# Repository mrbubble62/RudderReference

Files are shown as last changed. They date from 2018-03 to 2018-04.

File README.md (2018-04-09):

# Rudder Reference
Low cost NMEA 2000 compatible rudder reference.

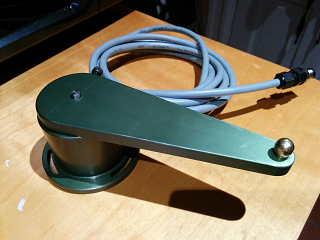
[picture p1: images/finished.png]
Finished
   

## PGN's sent 
127245 Rudder angle in radians every 250ms.

## Initial calibration via USB serial
Center the sensor and press 'z' to set zero angle, turn 90 degrees and use the + and - keys to adjust gain.

## Zero setting in vessel
Center the rudder and from an MFD change the device instance to 200.
The current setting will be stored in EEPROM as the zero point.
The device will return to the prevoiusly set N2K device instance, this may confuse the MFD so power cycle the system.

### Tested Hardware
- Teensy 3.2
- MCP2562 CAN Transceiver
- LM7805 5V Linear regulator
- 0.25A Poly fuse
- 5K ohm Linear 0.1% WDD35D4-5K Angle Sensors

## Notes
WDD35D4 Angle Sensor potentiometers claim a reliable plastic track with good linearity and are availible on eBay for ~$10.
Teensy ADC is good for 12-13bits giving a resolution of 0.04-0.08 degrees.

## Prototype images
Ugly but functional prototype  
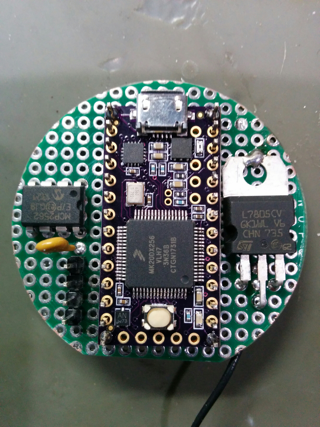
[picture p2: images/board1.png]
   
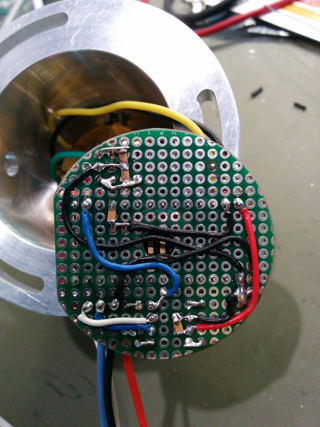
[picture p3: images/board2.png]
   
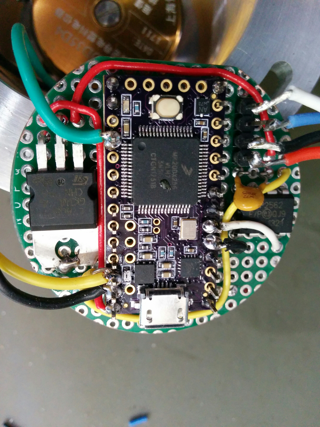
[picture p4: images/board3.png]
   
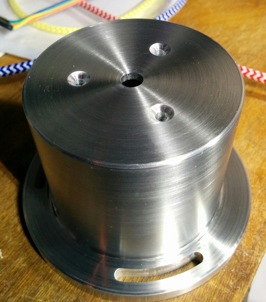
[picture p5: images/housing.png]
   
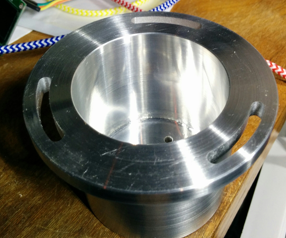
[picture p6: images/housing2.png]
   
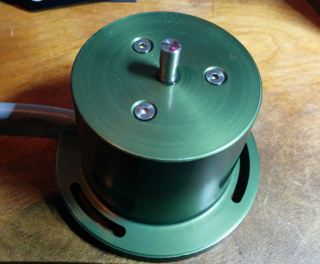
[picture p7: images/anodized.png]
   
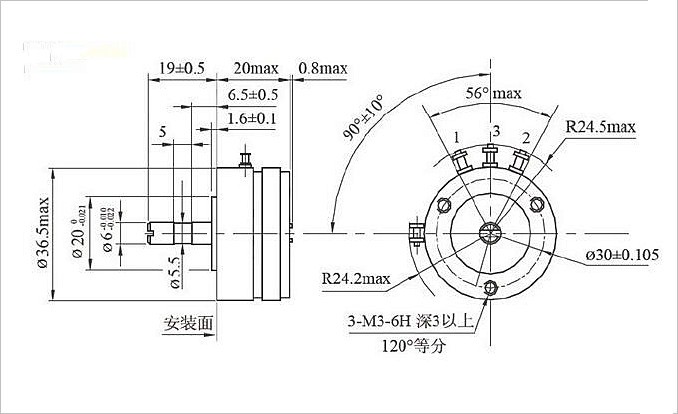
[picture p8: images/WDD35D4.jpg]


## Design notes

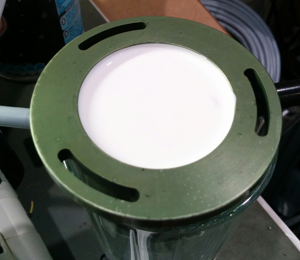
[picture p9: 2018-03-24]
images/RTV.png

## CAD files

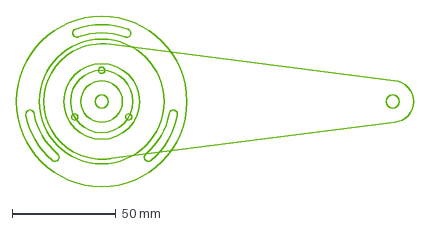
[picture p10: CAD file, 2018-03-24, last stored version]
RudderRefrence.dxf
191.0 x 82.0 mm

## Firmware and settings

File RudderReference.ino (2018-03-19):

#include "NMEA2000_CAN.h"
#include "N2kMessages.h"
#include <EEPROM.h>
#include <ADC_Module.h>
#include <ADC.h>

#define EEPROM_ADDR_CONFIG 0 // starting eeprom address for config params (Teensy 2K EEPROM) 
#define STDBYPIN 14 // MCP2562 CAN tranciver standby
#define ADCRESOLUTION 16
#define DEG2RAD 0.01745329252
#define ADCNUM 1 // ADC 1 seems slightly less noisy
const uint8_t ADCPIN = PIN_A2; // ADC0 or 1
double scale = 0.00950; // volts per degree
double VREF = 3.307;	// measured ADC Reference voltage
double offsetVoltage;	// center point voltage offset
double position;		//angle in degrees
uint16_t adcCount = 0; // ADC value in counts
double volts = 0; // measured ADC voltage
double gain = 1.000;  // sensor gain  compensate for potentiometer accuracy 5K 5%
ADC* adc = new ADC();
float average = 0;
const int NUM_AVGS = 100;

// VREF_OUT test function
float GetVREF() {
	average = 0;
	for (int i = 0; i<NUM_AVGS; i++) {
		average += 1.195 / adc->analogRead(ADC_INTERNAL_SOURCE::VREF_OUT, ADCNUM)*(adc->getMaxValue(ADCNUM));
	}
	return average / NUM_AVGS;
}

// VREFH test function
float GetVREFH() {
	average = 0;
	for (int i = 0; i<NUM_AVGS; i++) {
		average += VREF / adc->analogRead(ADC_INTERNAL_SOURCE::VREFH, ADCNUM)*(adc->getMaxValue(ADCNUM));
	}
	return average / NUM_AVGS;
}

// EEPROM configuration structure
#define MAGIC 12345 // EPROM struct version check, change this whenever tConfig structure changes
struct tConfig {
	uint16_t Magic; //test if eeprom initialized
	double Zero;
	double Gain;
	uint8_t deviceInstance;
};

// EEPROM contents
tConfig config;

// Default EEPROM contents
const tConfig defConfig PROGMEM = {
	MAGIC,
	VREF/2, // zero
	1,  // unity gain
	50	// deviceInstance
};

//*****************************************************************************
tN2kMsg N2kMsg; // N2K message constructor
const unsigned long TransmitMessages[] PROGMEM = { 127245L, 0 }; //Rudder Angle																						   // 	Received Messages			

void setup() {
	pinMode(LED_BUILTIN, OUTPUT); //enable LED
	pinMode(STDBYPIN, OUTPUT);  // take CAN chip out of standby
	digitalWrite(STDBYPIN, LOW);
	pinMode(ADCPIN, INPUT);
	Serial.begin(115200);
	Blink(10, 250); //delay for 1 sec and flash LED

	adc->setReference(ADC_REFERENCE::REF_3V3, ADCNUM);
	adc->setAveraging(32, ADCNUM);
	adc->setResolution(ADCRESOLUTION, ADCNUM);
	adc->setConversionSpeed(ADC_CONVERSION_SPEED::VERY_LOW_SPEED, ADCNUM);
	adc->setSamplingSpeed(ADC_SAMPLING_SPEED::VERY_LOW_SPEED, ADCNUM);
	adc->startContinuous(ADCPIN, ADCNUM);
	delay(100);
	Serial.println(F("STARTING"));
	ReadConfig();
	if (config.Magic != MAGIC) {
		InitializeEEPROM();
		Serial.println(F("No stored calibration..\n"));
		delay(5000);
	}
	else {
		Serial.println(F("Loading stored calibration..\n"));
		PrintConfig();
		gain = config.Gain;
		offsetVoltage = config.Zero;
	}
	
	// report the supply voltages
	Serial.print(F("3.3V ADC reference : "));
	Serial.print(GetVREFH(),4);
	Serial.println("V");
	Serial.print("VREF OUT voltage: ");
	Serial.print(GetVREF(), 4);
	Serial.println("V");	delay(2000);

	// Setup NMEA2000
	NMEA2000.SetInstallationDescription1("Mr Bubble Rudder Reference");
	NMEA2000.SetProductInformation("20180317", // Manufacturer's Model serial code
		669, // Manufacturer's product code
		"Rudder Reference",  // Manufacturer's Model ID
		"1.0.0.0",  // Manufacturer's Software version code
		"1.0.0.0", // Manufacturer's Model version
		2,	// load equivalency *50ma
		0xffff, // NMEA 2000 version - use default
		0xff // Sertification level - use default
	);
	// Set device information
	NMEA2000.SetDeviceInformation(20180317, // Unique number. Use e.g. Serial number.
		155, // Device function=Environment See codes on http://www.nmea.org/Assets/20120726%20nmea%202000%20class%20%26%20function%20codes%20v%202.00.pdf
		40, // Device class=Sensor Communication Interface. See codes on http://www.nmea.org/Assets/20120726%20nmea%202000%20class%20%26%20function%20codes%20v%202.00.pdf
		2040, // Just choosen free from code list on http://www.nmea.org/Assets/20121020%20nmea%202000%20registration%20list.pdf                               
		4 // marine industry
	);
	NMEA2000.SetMode(tNMEA2000::N2km_NodeOnly, config.deviceInstance);
	NMEA2000.EnableForward(false);
	NMEA2000.ExtendTransmitMessages(TransmitMessages);
	NMEA2000.SetN2kCANMsgBufSize(5);
	NMEA2000.Open();
	PrintHelp();
}

// loop controls
uint32_t delt_t = 0; // 250 ms loop
uint32_t count = 0; // 250 ms loop
long slowloop = 0; // 1s loop

// USB serial commands
bool SDEBUG = false; // toggle debug print
bool SDATA = false; // toggle data print
int GAIN; // gain switch

void loop() {
	char command = getCommand();
	switch (command) {
	case '+':
		GAIN = 1;
		break;
	case '-':
		GAIN = -1;
		break;
	case 'd':
		SDEBUG = !SDEBUG;
		break;
	case 'w':
		config.Gain = gain;
		UpdateConfig();
		break;
	case 'z': 
		offsetVoltage = volts;
		config.Zero = offsetVoltage;
		UpdateConfig();
		break;
	default:
		break;
	}

	if (adc->isComplete(ADCNUM)) {
		adcCount = (uint16_t)adc->analogReadContinuous(ADCNUM);
	}

	// 250ms 
	delt_t = millis() - count;
	if (delt_t > 250) { // fast update once per 250ms independent of read rate
		count = millis();
		digitalWrite(LED_BUILTIN, LOW);

		if (GAIN != 0) {
			SDATA = true;
			gain += (gain / 500)*GAIN;
			Serial.print("GAIN: ");
			Serial.println(gain);
			GAIN = 0;
		}

		volts = adcCount * VREF / (double)adc->getMaxValue(ADCNUM);
		position = gain * (volts - offsetVoltage)/scale;
		
		// debug
		if (SDEBUG) { printDebug(); }
		if (SDATA) { print(); }

		// send rudder angle 
		SetN2kRudder(N2kMsg, position*DEG2RAD);
		NMEA2000.SendMsg(N2kMsg);

		slowloop++;
	}
	// 1000ms
	if (slowloop > 3) { slowloop = 0; SlowLoop(); }
	NMEA2000.ParseMessages();
}

// slow message loop
void SlowLoop() {
	// Slow loop N2K message processing
	// check device instance for instructions from MFD
	tNMEA2000::tDeviceInformation DeviceInformation = NMEA2000.GetDeviceInformation();
	uint8_t DeviceInstance = DeviceInformation.GetDeviceInstance();
	if (DeviceInstance != config.deviceInstance) {
		// set instance to 200 to set midship zero angle point.
		if (DeviceInstance == 200) {
			Serial.println("\nSetting zero point");
			offsetVoltage = volts;
			config.Zero = offsetVoltage;
			UpdateConfig();
			DeviceInstance = config.deviceInstance;
			DeviceInformation.SetDeviceInstance(DeviceInstance);
			Blink(20, 150);
		}
		else {
			Serial.print("\nInstance changed to: "); Serial.print(DeviceInstance);
			config.deviceInstance = DeviceInstance;
			UpdateConfig();
		}
	}
	digitalWrite(LED_BUILTIN, HIGH);
}

// read serial input
char getCommand()
{
	char c = '\0';
	if (Serial.available())
	{
		c = Serial.read();
	}
	return c;
}

//*****************************************************************************
// LED blinker count flashes in duration ms
void Blink(int count, unsigned long duration) {
	unsigned long d = duration / count;
	for (int counter = 0; counter < count; counter++) {
		digitalWrite(LED_BUILTIN, HIGH);
		delay(d / 2);
		digitalWrite(LED_BUILTIN, LOW);
		delay(d / 2);
	}
}

// EEPROM *****************************************************************************
//Load From EEPROM 
void ReadConfig() {
	EEPROM.get(EEPROM_ADDR_CONFIG, config);
}

//Write to EEPROM - Teensy non-volatile area size is 2048 bytes  100,000 cycles
void UpdateConfig() {
	Blink(5, 2000);
	Serial.println("Updating config");
	config.Magic = MAGIC;
	EEPROM.put(EEPROM_ADDR_CONFIG, config);
}

// Load default config into EEPROM
void InitializeEEPROM() {
	Serial.println("Initialize EEPROM");
	config = defConfig;
	UpdateConfig();
}

void print(){
	Serial.print("Rudder Angle: ");
	Serial.print(position);
	Serial.print(" deg ");
	Serial.print(position*DEG2RAD,4);
	Serial.println(" rad");
}

void printDebug() {
	Serial.print("ADC count: ");
	Serial.print(adcCount);
	Serial.print(" Abs: ");
	Serial.print(volts,4);
	Serial.print("V Rel: ");
	Serial.print(volts - offsetVoltage,4);
	Serial.print("V Offset: ");
	Serial.print(offsetVoltage, 4);
	Serial.print(" Gain: ");
	Serial.print(gain,4);
	Serial.print(" ");
}

void PrintConfig() {
	Serial.print("Center zero offset: ");
	Serial.print(offsetVoltage);
	Serial.print("V\n");
	Serial.print("Gain: ");
	Serial.print(gain, 6);
	Serial.println("\n");
}

void PrintHelp()
{
	Serial.println(F("Mr Bubble Rudder Reference"));
	Serial.println(F("Commands: \"p\"=show data, \"d\"=show ADC voltages, \"z\"=save current position as zero reference, \"+\"=ingrease gain,\"-\"=decrease gain, \"w\"=save gain setting to EEPROM"));
	Serial.println(F("Alignment: Center the wheel and press 'z' to align the rudder reference, turn to 90 degrees and use the + and - keys to adjust gain"));
}

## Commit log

2018-03-18 NMEA 2000 compatible rudder reference initial commit
2018-03-19 prototype images
    Not pretty but functional
2018-03-24 Added more images and CAM files
    [RudderRefrence.dxf]
2018-03-24 WDD35D4-5K CAD
2018-03-25 more images
    moved images
    [RudderRefrence.dxf]
